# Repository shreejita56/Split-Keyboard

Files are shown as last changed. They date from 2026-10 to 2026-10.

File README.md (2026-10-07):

# Split-Keyboard



SO I made a custom 60 % layout  Split Mechanical keyboard which has a rotor encoder at the top for brightness controlee as well . It is based on Xiao rp2040 . As it has very few pins So I had to use 2 Expanders one for each Split . The communication between 2 Splits happens with the USB-C to USB-C Connection. And We hade intricated per switch LEDs as  well . The Split Keyboard have magnets by the side SO that we could join the split and make it a big single keyboard if we want or use it as a split.  The PCB was designed on kicad and CAD was done on Fusion . firmware was written in VS-Code. It has a very compact design. The Keyboard also includes per switch LED and diodes to prevent ghosting. 

## Features

 - Based on Xiao Rp2040
 - It has A split Keyboard Design
 - had compact 60% keyboard layout
 - Per Switch LED and diode for ghosting prevention
 - Uplifted CAD Design for comfortable typing
 - Has magnets at the Edges So that the Split could be connected and used as a Simple Keyboard
   
## BOM

| Item | Price (USD) | Source |
|---|---:|---|
| PCB + Shipping + 3D Prints - Coupons | $23.14 | https://jlcpcb.com/|
| KeyCaps | $15.04 | https://meckeys.com/shop/accessories/keyboard-accessories/keycaps/ranuw-keycap-set/ |
| Stabilizers | $10.76 | https://meckeys.com/shop/accessories/keyboard-accessories/more/glorious-goat-stabilizers/ |
| Switches (Pack of 10) × 7 | $22.10 | https://meckeys.com/shop/accessories/keyboard-accessories/key-switches/hmx-xinhai-switch/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|
| PCA9555 Expander × 2 | $6.22 | https://robu.in/product/pca9555dwr-texas-instruments-400khz-soic-24-300mil-i-o-expanders-rohs/ |
| Seeed Studio XIAO RP2040 | $5.92 | https://robu.in/product/seeed-studio-xiao-rp2040-v1-0/ |
| 1N4148W-T4 Diodes (Pack of 15) × 70 | $3.20 | https://sharvielectronics.com/product/a7-1n4007-100v-1a-silicon-rectifier-diode-sod-123fl-smd-package/|
| SK6812MINI-E | $8.10 | https://www.etstore.in/products/e9974?variant=48993209319675|
| Components Shipping | $3.30 |https://sharvielectronics.com/ / https://meckeys.com / https://robu.in |
| **Total** | **$97.78** | |

### Schematic<br><br>



###  PCB Design<br><br>



### 3D Render <br><br>




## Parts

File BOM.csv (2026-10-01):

item | Price | Source
PCB + Shipping + 3D Prints - Coupons | 23.14 | JLCPCB
KeyCaps | 15.04 | https://meckeys.com/shop/accessories/keyboard-accessories/keycaps/ranuw-keycap-set/
Stabilizers | 10.76 | https://meckeys.com/shop/accessories/keyboard-accessories/more/glorious-goat-stabilizers/
Switches (pack of 10) x 7 | 22.1 | https://meckeys.com/shop/accessories/keyboard-accessories/key-switches/hmx-xinhai-switch/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
Expander x 2 | 6.22 | https://robu.in/product/pca9555dwr-texas-instruments-400khz-soic-24-300mil-i-o-expanders-rohs/
Rp-2040 | 5.92 | https://robu.in/product/seeed-studio-xiao-rp2040-v1-0/
1N4148W-T4 diodes (Pack of 15) X 70 | 3.2 | https://sharvielectronics.com/product/a7-1n4007-100v-1a-silicon-rectifier-diode-sod-123fl-smd-package/
SK6812MINI-E | 8.1 | https://www.etstore.in/products/e9974?variant=48993209319675
Components shipping (from all the three websites except jlcpcb) | 3.3 | https://sharvielectronics.com / https://meckeys.com / https://robu.in
Total | $97.78

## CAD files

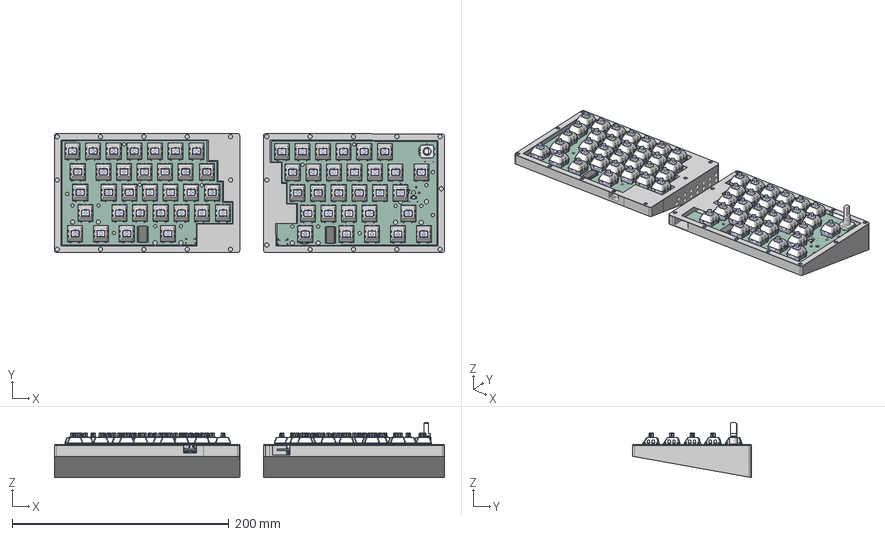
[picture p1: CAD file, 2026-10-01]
CAD/KY60.step
360.0 x 110.0 x 50.9 mm

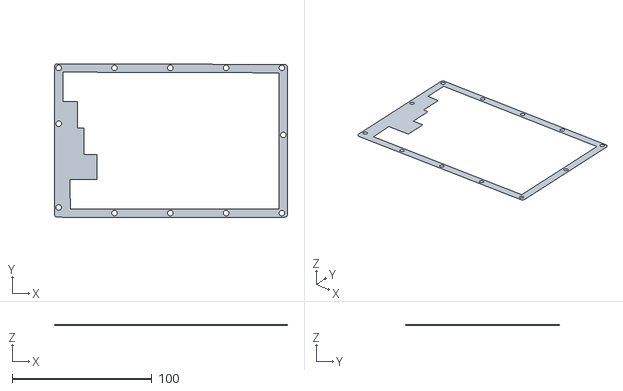
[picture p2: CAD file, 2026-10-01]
Production/CAD/TopRight.stl
167.0 x 110.0 x 0.5

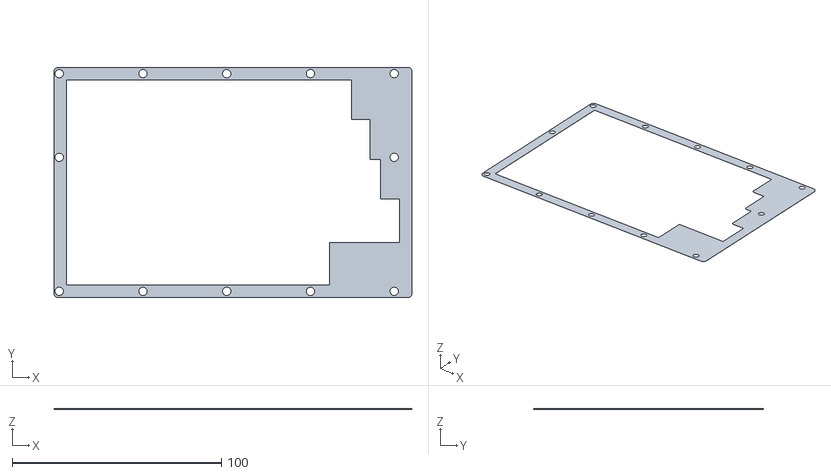
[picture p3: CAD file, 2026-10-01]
Production/CAD/TopLEFT.stl
171.0 x 110.0 x 0.5

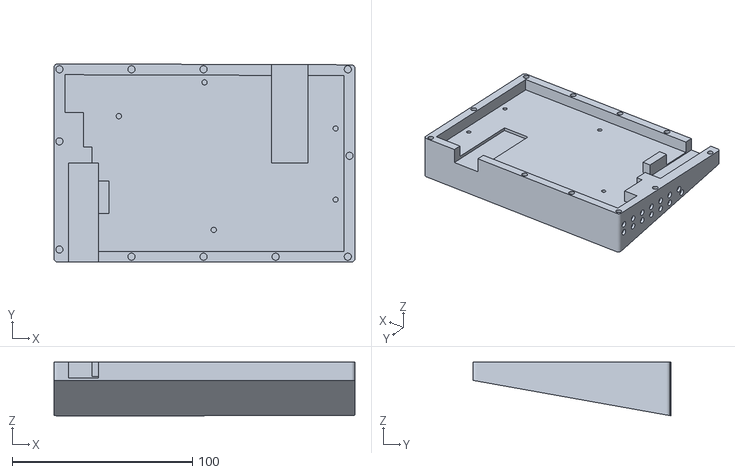
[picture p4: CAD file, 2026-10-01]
Production/CAD/BottomRight.stl
167.0 x 110.0 x 29.8

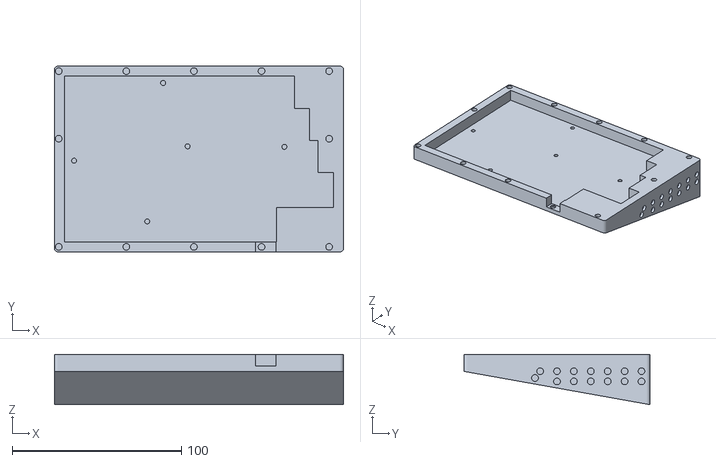
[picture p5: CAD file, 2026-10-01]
Production/CAD/BottomLeft.stl
171.0 x 110.0 x 29.8

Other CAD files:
CAD/KY60.f3d

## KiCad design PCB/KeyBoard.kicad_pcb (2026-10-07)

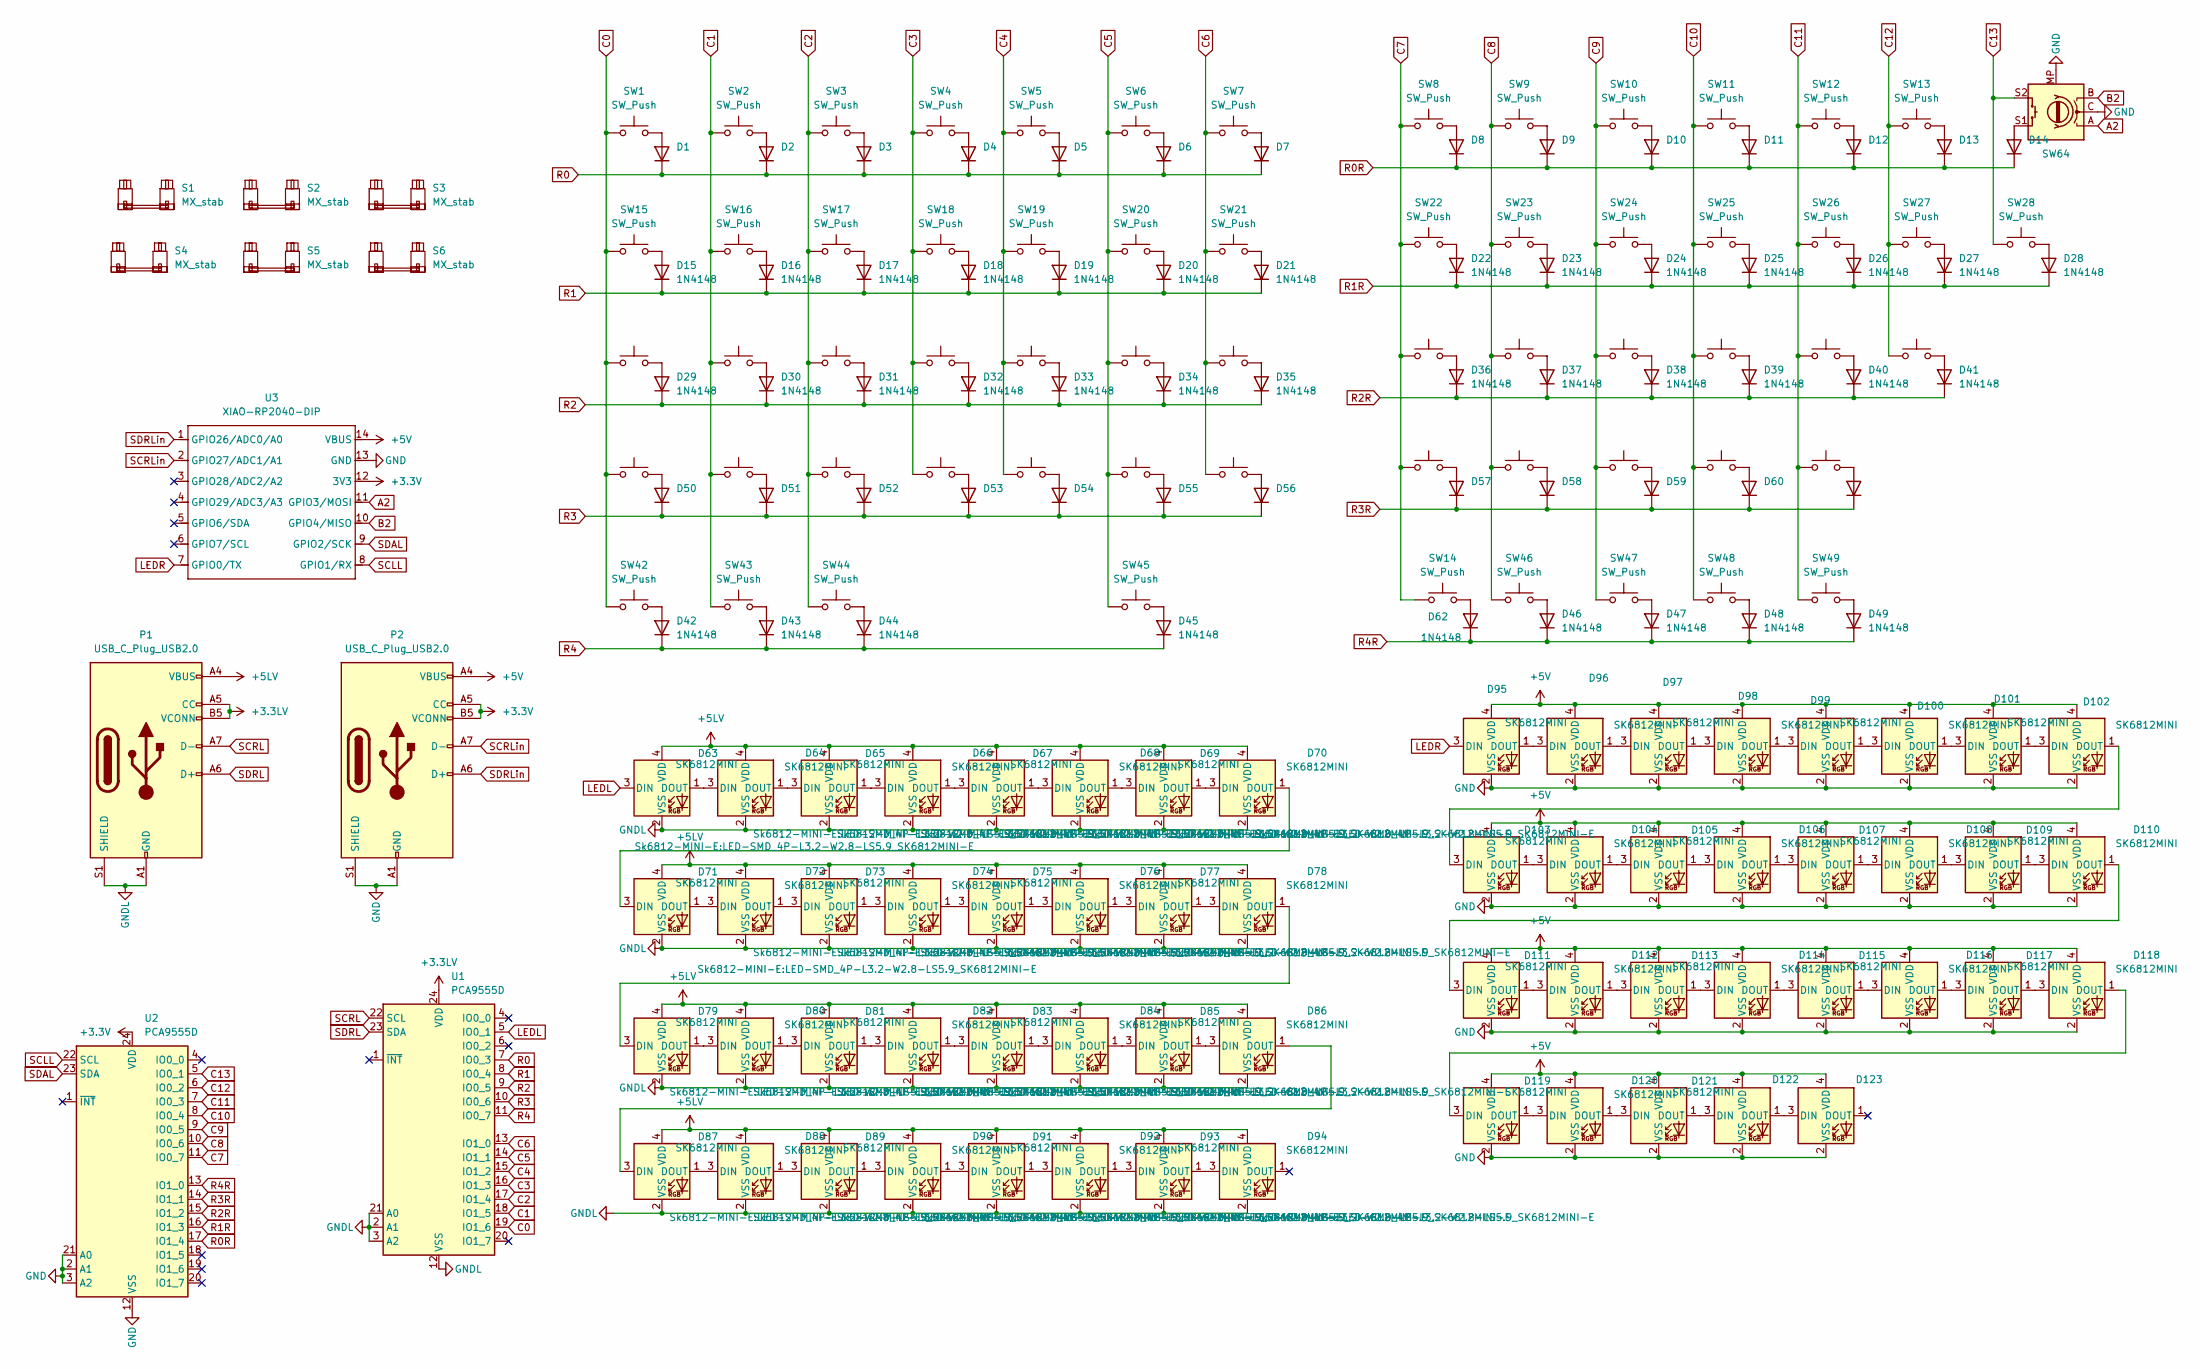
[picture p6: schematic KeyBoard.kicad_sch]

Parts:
D1, D2, D3, D4, D5, D6, D7, D8, D9, D10, D11, D12, D13, D14, D15, D16, D17, D18, D19, D20, D21, D22, D23, D24, D25, D26, D27, D28, D29, D30, D31, D32, D33, D34, D35, D36, D37, D38, D39, D40, D41, D42, D43, D44, D45, D46, D47, D48, D49, D50, D51, D52, D53, D54, D55, D56, D57, D58, D59, D60, D61, D62: 1N4148; D_DO-35_SOD27_P7.62mm_Horizontal
D63, D64, D65, D66, D67, D68, D69, D70, D71, D72, D73, D74, D75, D76, D77, D78, D79, D80, D81, D82, D83, D84, D85, D86, D87, D88, D89, D90, D91, D92, D93, D94, D95, D96, D97, D98, D99, D100, D101, D102, D103, D104, D105, D106, D107, D108, D109, D110, D111, D112, D113, D114, D115, D116, D117, D118, D119, D120, D121, D122, D123: SK6812MINI; LED-SMD_4P-L3.2-W2.8-LS5.9_SK6812MINI-E
P1, P2: USB_C_Plug_USB2.0; USB_C_Receptacle_HRO_TYPE-C-31-M-12
S1: MX_stab; STAB_MX_2u
S2, S3: MX_stab; STAB_MX_2.25u
S4, S5, S6: MX_stab; STAB_MX_2.75u
SW1, SW2, SW3, SW4, SW5, SW6, SW7, SW8, SW9, SW10, SW11, SW12, SW13, SW16, SW17, SW18, SW19, SW20, SW21, SW22, SW23, SW24, SW25, SW26, SW27, SW30, SW31, SW32, SW33, SW34, SW35, SW36, SW37, SW38, SW39, SW40, SW51, SW52, SW53, SW54, SW55, SW56, SW57, SW58, SW59, SW60: SW_Push; SW_Cherry_MX_1.00u_PCB
SW14, SW45, SW61: SW_Push; SW_Cherry_MX_2.75u_PCB
SW15: SW_Push; SW_Cherry_MX_1.50u_PCB
SW28: SW_Push; SW_Cherry_MX_1.50u_Plate
SW29: SW_Push; SW_Cherry_MX_1.75u_PCB
SW41, SW50: SW_Push; SW_Cherry_MX_2.25u_PCB
SW42, SW43, SW44, SW46, SW48, SW49: SW_Push; SW_Cherry_MX_1.25u_PCB
SW47: SW_Push; SW_Cherry_MX_1.25u_Plate
SW64: RotaryEncoder_Switch_MP; RotaryEncoder_Alps_EC11E-Switch_Vertical_H20mm
U1, U2: PCA9555D; SOIC-24W_7.5x15.4mm_P1.27mm
U3: XIAO-RP2040-DIP; XIAO-RP2040-SMD

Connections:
+3.3LV: P1.A5 (CC), P1.B5 (VCONN), U1.24 (VDD)
+3.3V: P2.A5 (CC), P2.B5 (VCONN), U2.24 (VDD), U3.12 (3V3)
+5LV: D63.4 (VDD), D64.4 (VDD), D65.4 (VDD), D66.4 (VDD), D67.4 (VDD), D68.4 (VDD), D69.4 (VDD), D70.4 (VDD), D71.4 (VDD), D72.4 (VDD), D73.4 (VDD), D74.4 (VDD), D75.4 (VDD), D76.4 (VDD), D77.4 (VDD), D78.4 (VDD), D79.4 (VDD), D80.4 (VDD), D81.4 (VDD), D82.4 (VDD), D83.4 (VDD), D84.4 (VDD), D85.4 (VDD), D86.4 (VDD), D87.4 (VDD), D88.4 (VDD), D89.4 (VDD), D90.4 (VDD), D91.4 (VDD), D92.4 (VDD), D93.4 (VDD), D94.4 (VDD), P1.A4 (VBUS), P1.A9 (VBUS), P1.B4 (VBUS), P1.B9 (VBUS)
+5V: D95.4 (VDD), D96.4 (VDD), D97.4 (VDD), D98.4 (VDD), D99.4 (VDD), D100.4 (VDD), D101.4 (VDD), D102.4 (VDD), D103.4 (VDD), D104.4 (VDD), D105.4 (VDD), D106.4 (VDD), D107.4 (VDD), D108.4 (VDD), D109.4 (VDD), D110.4 (VDD), D111.4 (VDD), D112.4 (VDD), D113.4 (VDD), D114.4 (VDD), D115.4 (VDD), D116.4 (VDD), D117.4 (VDD), D118.4 (VDD), D119.4 (VDD), D120.4 (VDD), D121.4 (VDD), D122.4 (VDD), D123.4 (VDD), P2.A4 (VBUS), P2.A9 (VBUS), P2.B4 (VBUS), P2.B9 (VBUS), U3.14 (VBUS)
A2: SW64.A, U3.11 (GPIO3/MOSI)
B2: SW64.B, U3.10 (GPIO4/MISO)
C0: SW1.1, SW15.1, SW29.1, SW42.1, SW50.1, U1.19 (IO1_6)
C1: SW2.1, SW16.1, SW30.1, SW43.1, SW51.1, U1.18 (IO1_5)
C2: SW3.1, SW17.1, SW31.1, SW44.1, SW52.1, U1.17 (IO1_4)
C3: SW4.1, SW18.1, SW32.1, SW53.1, U1.16 (IO1_3)
C4: SW5.1, SW19.1, SW33.1, SW54.1, U1.15 (IO1_2)
C5: SW6.1, SW20.1, SW34.1, SW45.1, SW55.1, U1.14 (IO1_1)
C6: SW7.1, SW21.1, SW35.1, SW56.1, U1.13 (IO1_0)
C7: SW8.1, SW14.1, SW22.1, SW36.1, SW57.1, U2.11 (IO0_7)
C8: SW9.1, SW23.1, SW37.1, SW46.1, SW58.1, U2.10 (IO0_6)
C9: SW10.1, SW24.1, SW38.1, SW47.1, SW59.1, U2.9 (IO0_5)
C10: SW11.1, SW25.1, SW39.1, SW48.1, SW60.1, U2.8 (IO0_4)
C11: SW12.1, SW26.1, SW40.1, SW49.1, SW61.1, U2.7 (IO0_3)
C12: SW13.1, SW27.1, SW41.1, U2.6 (IO0_2)
C13: SW28.1, SW64.S2, U2.5 (IO0_1)
GND: D95.2 (VSS), D96.2 (VSS), D97.2 (VSS), D98.2 (VSS), D99.2 (VSS), D100.2 (VSS), D101.2 (VSS), D102.2 (VSS), D103.2 (VSS), D104.2 (VSS), D105.2 (VSS), D106.2 (VSS), D107.2 (VSS), D108.2 (VSS), D109.2 (VSS), D110.2 (VSS), D111.2 (VSS), D112.2 (VSS), D113.2 (VSS), D114.2 (VSS), D115.2 (VSS), D116.2 (VSS), D117.2 (VSS), D118.2 (VSS), D119.2 (VSS), D120.2 (VSS), D121.2 (VSS), D122.2 (VSS), D123.2 (VSS), P2.A1 (GND), P2.A12 (GND), P2.B1 (GND), P2.B12 (GND), P2.S1 (SHIELD), SW64.C, SW64.MP, U2.2 (A1), U2.3 (A2), U2.12 (VSS), U2.21 (A0), U3.13 (GND)
GNDL: D63.2 (VSS), D64.2 (VSS), D65.2 (VSS), D66.2 (VSS), D67.2 (VSS), D68.2 (VSS), D69.2 (VSS), D70.2 (VSS), D71.2 (VSS), D72.2 (VSS), D73.2 (VSS), D74.2 (VSS), D75.2 (VSS), D76.2 (VSS), D77.2 (VSS), D78.2 (VSS), D79.2 (VSS), D80.2 (VSS), D81.2 (VSS), D82.2 (VSS), D83.2 (VSS), D84.2 (VSS), D85.2 (VSS), D86.2 (VSS), D87.2 (VSS), D88.2 (VSS), D89.2 (VSS), D90.2 (VSS), D91.2 (VSS), D92.2 (VSS), D93.2 (VSS), D94.2 (VSS), P1.A1 (GND), P1.A12 (GND), P1.B1 (GND), P1.B12 (GND), P1.S1 (SHIELD), U1.2 (A1), U1.3 (A2), U1.12 (VSS), U1.21 (A0)
LEDL: D63.3 (DIN), U1.5 (IO0_1)
LEDR: D95.3 (DIN), U3.7 (GPIO0/TX)
unnamed: D1.2 (A), SW1.2
unnamed: D2.2 (A), SW2.2
unnamed: D3.2 (A), SW3.2
unnamed: D4.2 (A), SW4.2
unnamed: D5.2 (A), SW5.2
unnamed: D6.2 (A), SW6.2
unnamed: D7.2 (A), SW7.2
unnamed: D8.2 (A), SW8.2
unnamed: D9.2 (A), SW9.2
unnamed: D10.2 (A), SW10.2
unnamed: D11.2 (A), SW11.2
unnamed: D12.2 (A), SW12.2
unnamed: D13.2 (A), SW13.2
unnamed: D14.2 (A), SW64.S1
unnamed: D15.2 (A), SW15.2
unnamed: D16.2 (A), SW16.2
unnamed: D17.2 (A), SW17.2
unnamed: D18.2 (A), SW18.2
unnamed: D19.2 (A), SW19.2
unnamed: D20.2 (A), SW20.2
unnamed: D21.2 (A), SW21.2
unnamed: D22.2 (A), SW22.2
unnamed: D23.2 (A), SW23.2
unnamed: D24.2 (A), SW24.2
unnamed: D25.2 (A), SW25.2
unnamed: D26.2 (A), SW26.2
unnamed: D27.2 (A), SW27.2
unnamed: D28.2 (A), SW28.2
unnamed: D29.2 (A), SW29.2
unnamed: D30.2 (A), SW30.2
unnamed: D31.2 (A), SW31.2
unnamed: D32.2 (A), SW32.2
unnamed: D33.2 (A), SW33.2
unnamed: D34.2 (A), SW34.2
unnamed: D35.2 (A), SW35.2
unnamed: D36.2 (A), SW36.2
unnamed: D37.2 (A), SW37.2
unnamed: D38.2 (A), SW38.2
unnamed: D39.2 (A), SW39.2
unnamed: D40.2 (A), SW40.2
unnamed: D41.2 (A), SW41.2
unnamed: D42.2 (A), SW42.2
unnamed: D43.2 (A), SW43.2
unnamed: D44.2 (A), SW44.2
unnamed: D45.2 (A), SW45.2
unnamed: D46.2 (A), SW46.2
unnamed: D47.2 (A), SW47.2
unnamed: D48.2 (A), SW48.2
unnamed: D49.2 (A), SW49.2
unnamed: D50.2 (A), SW50.2
unnamed: D51.2 (A), SW51.2
unnamed: D52.2 (A), SW52.2
unnamed: D53.2 (A), SW53.2
unnamed: D54.2 (A), SW54.2
unnamed: D55.2 (A), SW55.2
unnamed: D56.2 (A), SW56.2
unnamed: D57.2 (A), SW57.2
unnamed: D58.2 (A), SW58.2
unnamed: D59.2 (A), SW59.2
unnamed: D60.2 (A), SW60.2
unnamed: D61.2 (A), SW61.2
unnamed: D62.2 (A), SW14.2
unnamed: D63.1 (DOUT), D64.3 (DIN)
unnamed: D64.1 (DOUT), D65.3 (DIN)
unnamed: D65.1 (DOUT), D66.3 (DIN)
unnamed: D66.1 (DOUT), D67.3 (DIN)
unnamed: D67.1 (DOUT), D68.3 (DIN)
unnamed: D68.1 (DOUT), D69.3 (DIN)
unnamed: D69.1 (DOUT), D70.3 (DIN)
unnamed: D70.1 (DOUT), D71.3 (DIN)
unnamed: D71.1 (DOUT), D72.3 (DIN)
unnamed: D72.1 (DOUT), D73.3 (DIN)
unnamed: D73.1 (DOUT), D74.3 (DIN)
unnamed: D74.1 (DOUT), D75.3 (DIN)
unnamed: D75.1 (DOUT), D76.3 (DIN)
unnamed: D76.1 (DOUT), D77.3 (DIN)
unnamed: D77.1 (DOUT), D78.3 (DIN)
unnamed: D78.1 (DOUT), D79.3 (DIN)
unnamed: D79.1 (DOUT), D80.3 (DIN)
unnamed: D80.1 (DOUT), D81.3 (DIN)
unnamed: D81.1 (DOUT), D82.3 (DIN)
unnamed: D82.1 (DOUT), D83.3 (DIN)
unnamed: D83.1 (DOUT), D84.3 (DIN)
unnamed: D84.1 (DOUT), D85.3 (DIN)
unnamed: D85.1 (DOUT), D86.3 (DIN)
unnamed: D86.1 (DOUT), D87.3 (DIN)
unnamed: D87.1 (DOUT), D88.3 (DIN)
unnamed: D88.1 (DOUT), D89.3 (DIN)
unnamed: D89.1 (DOUT), D90.3 (DIN)
unnamed: D90.1 (DOUT), D91.3 (DIN)
unnamed: D91.1 (DOUT), D92.3 (DIN)
unnamed: D92.1 (DOUT), D93.3 (DIN)
unnamed: D93.1 (DOUT), D94.3 (DIN)
unnamed: D95.1 (DOUT), D96.3 (DIN)
unnamed: D96.1 (DOUT), D97.3 (DIN)
unnamed: D97.1 (DOUT), D98.3 (DIN)
unnamed: D98.1 (DOUT), D99.3 (DIN)
unnamed: D99.1 (DOUT), D100.3 (DIN)
unnamed: D100.1 (DOUT), D101.3 (DIN)
unnamed: D101.1 (DOUT), D102.3 (DIN)
unnamed: D102.1 (DOUT), D103.3 (DIN)
unnamed: D103.1 (DOUT), D104.3 (DIN)
unnamed: D104.1 (DOUT), D105.3 (DIN)
unnamed: D105.1 (DOUT), D106.3 (DIN)
unnamed: D106.1 (DOUT), D107.3 (DIN)
unnamed: D107.1 (DOUT), D108.3 (DIN)
unnamed: D108.1 (DOUT), D109.3 (DIN)
unnamed: D109.1 (DOUT), D110.3 (DIN)
unnamed: D110.1 (DOUT), D111.3 (DIN)
unnamed: D111.1 (DOUT), D112.3 (DIN)
unnamed: D112.1 (DOUT), D113.3 (DIN)
unnamed: D113.1 (DOUT), D114.3 (DIN)
unnamed: D114.1 (DOUT), D115.3 (DIN)
unnamed: D115.1 (DOUT), D116.3 (DIN)
unnamed: D116.1 (DOUT), D117.3 (DIN)
unnamed: D117.1 (DOUT), D118.3 (DIN)
unnamed: D118.1 (DOUT), D119.3 (DIN)
unnamed: D119.1 (DOUT), D120.3 (DIN)
unnamed: D120.1 (DOUT), D121.3 (DIN)
unnamed: D121.1 (DOUT), D122.3 (DIN)
unnamed: D122.1 (DOUT), D123.3 (DIN)
R0: D1.1 (K), D2.1 (K), D3.1 (K), D4.1 (K), D5.1 (K), D6.1 (K), D7.1 (K), U1.7 (IO0_3)
R0R: D8.1 (K), D9.1 (K), D10.1 (K), D11.1 (K), D12.1 (K), D13.1 (K), D14.1 (K), U2.17 (IO1_4)
R1: D15.1 (K), D16.1 (K), D17.1 (K), D18.1 (K), D19.1 (K), D20.1 (K), D21.1 (K), U1.8 (IO0_4)
R1R: D22.1 (K), D23.1 (K), D24.1 (K), D25.1 (K), D26.1 (K), D27.1 (K), D28.1 (K), U2.16 (IO1_3)
R2: D29.1 (K), D30.1 (K), D31.1 (K), D32.1 (K), D33.1 (K), D34.1 (K), D35.1 (K), U1.9 (IO0_5)
R2R: D36.1 (K), D37.1 (K), D38.1 (K), D39.1 (K), D40.1 (K), D41.1 (K), U2.15 (IO1_2)
R3: D50.1 (K), D51.1 (K), D52.1 (K), D53.1 (K), D54.1 (K), D55.1 (K), D56.1 (K), U1.10 (IO0_6)
R3R: D57.1 (K), D58.1 (K), D59.1 (K), D60.1 (K), D61.1 (K), U2.14 (IO1_1)
R4: D42.1 (K), D43.1 (K), D44.1 (K), D45.1 (K), U1.11 (IO0_7)
R4R: D46.1 (K), D47.1 (K), D48.1 (K), D49.1 (K), D62.1 (K), U2.13 (IO1_0)
SCLL: U2.22 (SCL), U3.8 (GPIO1/RX)
SCRL: P1.A7 (D-), U1.22 (SCL)
SCRLin: P2.A7 (D-), U3.2 (GPIO27/ADC1/A1)
SDAL: U2.23 (SDA), U3.9 (GPIO2/SCK)
SDRL: P1.A6 (D+), U1.23 (SDA)
SDRLin: P2.A6 (D+), U3.1 (GPIO26/ADC0/A0)

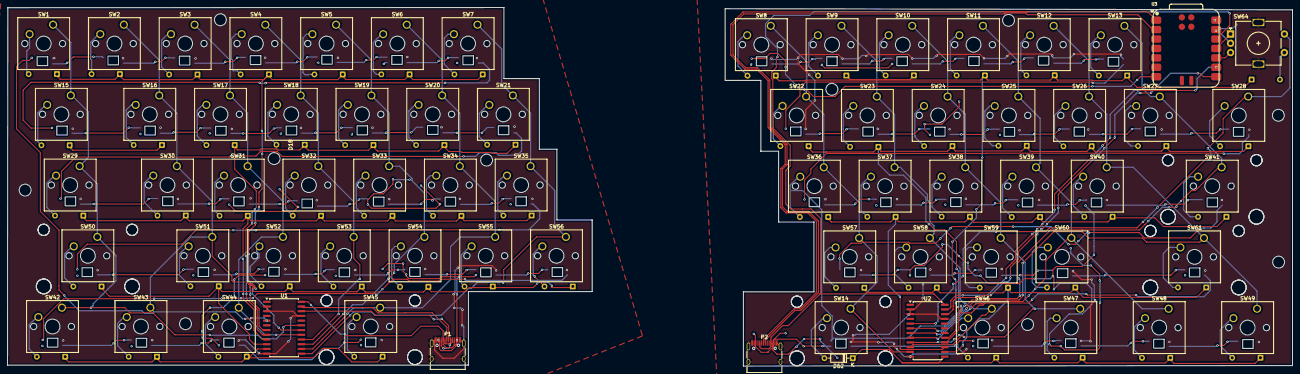
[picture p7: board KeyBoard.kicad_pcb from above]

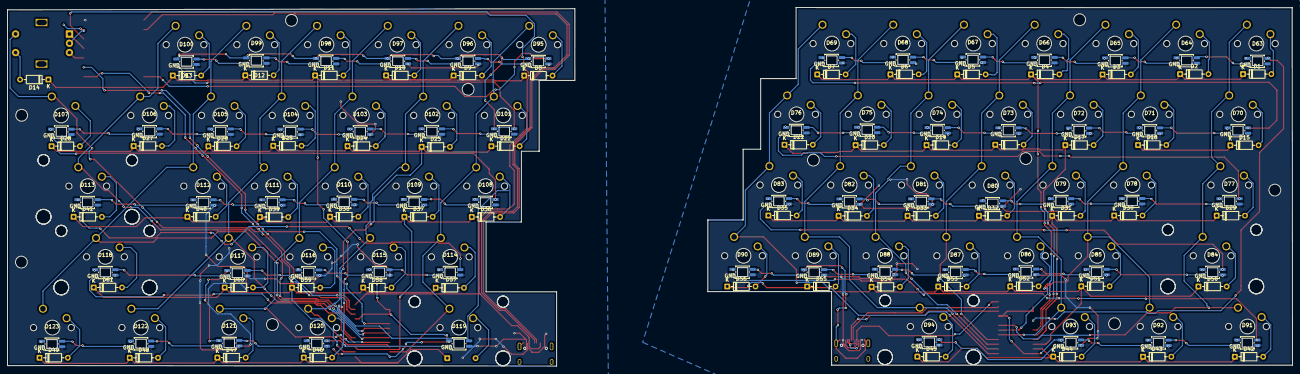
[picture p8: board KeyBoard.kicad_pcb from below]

Board: 2 copper layers, 346.1 x 96.6 mm, 195 parts (122 on the bottom side), 161 nets.

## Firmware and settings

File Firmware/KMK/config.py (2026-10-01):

# Hardware mapping for the Rocket split keyboard.
#
# From the schematic:
#   U1 = PCA9555, A0/A1/A2 -> GND -> 0x20, bus SCL1/SDA1
#   U2 = PCA9555, A0/A1/A2 -> GND -> 0x20, bus SCL/SDA
#
# The two 0x20 devices MUST be on different I2C buses.
#
# Change ONLY the GPIO numbers below if your RP2040 routes the
# SCL/SDA nets to different GPIOs.

# Bus for the PCA9555 connected to SCL/SDA
I2C0_SDA_GPIO = 6
I2C0_SCL_GPIO = 7

# Bus for the PCA9555 connected to SCL1/SDA1
# Common RP2040 I2C1 routing used by many boards:
I2C1_SDA_GPIO = 20
I2C1_SCL_GPIO = 21

PCA9555_U2_ADDRESS = 0x20   # SCL/SDA
PCA9555_U1_ADDRESS = 0x20   # SCL1/SDA1

# Matrix connections visible in the schematic are exposed as
# PCA9555 port pins here. Adjust only if your net labels differ.
# U2 (SCL/SDA expander)
U2_ROWS = [0, 1, 2, 3, 4]
U2_COLS = [8, 9, 10, 11, 12, 13, 14, 15]

# U1 (SCL1/SDA1 expander)
U1_ROWS = [0, 1, 2, 3, 4]
U1_COLS = [8, 9, 10, 11, 12, 13, 14, 15]

DIODE_DIRECTION = "COL2ROW"

# Your direct LED data line.
# NOTE: if this means RP2040 GPIO7, it conflicts with I2C0_SCL_GPIO=7.
# In that case move I2C0_SCL_GPIO to the GPIO actually labelled SCL in
# your PCB/schematic. Do NOT run LED data and I2C SCL on the same GPIO.
LED_DATA_GPIO = 7

ENCODER_A_GPIO = 4
ENCODER_B_GPIO = 5
ENCODER_BUTTON_GPIO = 3

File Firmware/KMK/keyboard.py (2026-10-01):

import board
import busio
from kmk.kmk_keyboard import KMKKeyboard
from kmk.keys import KC
from kmk.modules.layers import Layers
from kmk.modules.encoder import EncoderHandler

from pca9555 import PCA9555, PCA9555Pin
from config import *

def GP(n):
    return getattr(board, "GP"+str(n))

def make_i2c(scl_gpio,sda_gpio):
    return busio.I2C(GP(scl_gpio),GP(sda_gpio),frequency=400000)

# SCL/SDA expander (U2)
i2c0=make_i2c(I2C0_SCL_GPIO,I2C0_SDA_GPIO)
# SCL1/SDA1 expander (U1)
i2c1=make_i2c(I2C1_SCL_GPIO,I2C1_SDA_GPIO)

u2=PCA9555(i2c0,PCA9555_U2_ADDRESS)
u1=PCA9555(i2c1,PCA9555_U1_ADDRESS)

keyboard=KMKKeyboard()
keyboard.modules.append(Layers())

# Expose expander pins for the matrix.
# Each half has its own PCA9555 and therefore its own 0x20 address.
u2_rows=[PCA9555Pin(u2,p) for p in U2_ROWS]
u2_cols=[PCA9555Pin(u2,p) for p in U2_COLS]
u1_rows=[PCA9555Pin(u1,p) for p in U1_ROWS]
u1_cols=[PCA9555Pin(u1,p) for p in U1_COLS]

# The hardware uses two separate 5x8 matrices. The custom scanner
# below scans both PCA9555s as independent halves.
class DualPCA9555Scanner:
    def __init__(self):
        self.rows=(u2_rows,u1_rows)
        self.cols=(u2_cols,u1_cols)

    def scan_for_changes(self, keyboard):
        # MatrixScanner implementation is board/KMK-version dependent.
        # This object intentionally keeps the exact hardware mapping
        # together; use the project's KMK MatrixScanner if available.
        return []

# Rotary encoder
encoder=EncoderHandler()
encoder.pins=((GP(ENCODER_A_GPIO),GP(ENCODER_B_GPIO),None),)
encoder.map=((KC.VOLD,KC.VOLU),)
keyboard.modules.append(encoder)

keyboard.keymap=[[
    KC.ESC,
    KC.N1,KC.N2,KC.N3,KC.N4,KC.N5,KC.N6,KC.N7,KC.N8,KC.N9,KC.N0,
    KC.MINS,KC.EQL,KC.BSPC,
    KC.TAB,KC.Q,KC.W,KC.E,KC.R,KC.T,KC.Y,KC.U,KC.I,KC.O,KC.P,
    KC.LBRC,KC.RBRC,KC.BSLS,
    KC.CAPS,KC.A,KC.S,KC.D,KC.F,KC.G,KC.H,KC.J,KC.K,KC.L,
    KC.SCLN,KC.QUOT,KC.ENTER,
    KC.LSFT,KC.Z,KC.X,KC.C,KC.V,KC.B,KC.N,KC.M,KC.COMM,KC.DOT,
    KC.SLSH,KC.RSFT,
    KC.LCTL,KC.LGUI,KC.LALT,KC.SPC,KC.RALT,KC.RGUI,KC.APP,KC.RCTL
]]
